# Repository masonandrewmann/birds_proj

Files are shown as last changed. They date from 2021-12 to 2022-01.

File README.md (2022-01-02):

# Communication via Sound with Bird-Like Autonomous Agents
## Final Project for Interactive Music, MUSI 4670/6002 

### Video Demo: 
https://youtu.be/LeYnbbA8mWI

### Project Paper: 
https://github.com/masonandrewmann/birds_proj/blob/34f84f54d7a54a15b16ec71c6c1e4912c616cff0/final_paper.pdf

### Libraries used:

MCP DAC Library: https://github.com/exscape/electronics/tree/master/Arduino/Libraries/DAC_MCP49xx

BasicLinearAlgebra (to easily perform matrix multiplication in Markov Model): https://github.com/tomstewart89/BasicLinearAlgebra

Goertzel Algorithm inspiration: https://github.com/jacobrosenthal/Goertzel

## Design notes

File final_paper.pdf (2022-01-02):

# Communication via Sound with Bird-Like Autonomous Agents

### Mir Jeffres

Georgia Institute of Technology Atlanta, Georgia, USA

### Mason Mann

Georgia Institute of Technology Atlanta, Georgia, USA
mmann33@gatech.edu

ACM Reference Format:
Mir Jeffres and Mason Mann. 2021. Communication via Sound with Bird-Like Autonomous Agents. In Proceedings of ACM Conference (Conference’17). ACM, New York, NY, USA, 2 pages. https://doi.org/10.1145/nnnnnnn.nnnnnnn

### 1 CONCEPT

The concept of our project was to create a group of autonomous, self-contained physical objects that could sing to each other and hear each other singing and respond according to computational algorithms. The idea was that simple behavior could be programmed into each agent and that together, complex group behavior would arise. Agents would switch between a state where they are listening, and another state where they respond. During the listening state they would determine the loudest note that they heard and use that as the input to a first order Markov model. With all the agents separately playing single notes from the same Markov model, the idea was that the whole group behavior would be similar to that of a single entity playing a single Markov-model. We considered this to be a sort of “distributed Markov model.” Additionally the average loudness that each agent is hearing at any given time will have an effect on the way it plays the notes. When the average loudness is higher, they will shorten their listening period, playing notes more often and moving through the markov model more quickly, and they will also play shorter notes creating a frantic feel. Additionally there would be a few ways that a user could interact and guide the behavior. The primary method of interaction is simply picking up the agents and moving them, if they are further apart from each other they will not hear each other as loudly, decreasing the average loudness and when far enough away, making some agents not interact at all. Another way that the users interact is through a special agent called the “Leader Bird.” This agent plays a special command pitch when a button on it is pressed. All of the follower agents have four separate Markov models built on different pitch-class sets and they all start on the same one. When an agent hears this command pitch they will move to the next pitch-class set. Since they might not all hear the command pitch depending on where they are placed, they will likely begin to drift into groups playing different pitch-class sets moving from a state of consonance in the beginning of the piece to a polytonal cloud as time goes on.

Permission to make digital or hard copies of all or part of this work for personal or classroom use is granted without fee provided that copies are not made or distributed for profit or commercial advantage and that copies bear this notice and the full citation on the first page. Copyrights for components of this work owned by others than ACM must be honored. Abstracting with credit is permitted. To copy otherwise, or republish, to post on servers or to redistribute to lists, requires prior specific permission and/or a fee. Request permissions from permissions@acm.org.
Conference’17, July 2017, Washington, DC, USA
© 2021 Association for Computing Machinery.
ACM ISBN 978-x-xxxx-xxxx-x/YY/MM. . . $15.00 https://doi.org/10.1145/nnnnnnn.nnnnnnn

### 2 CONTEXT

The work that most directly inspired this project was Felix Hess’s Electronic Sound Creatures. In his project, one hundred physical autonomous agents were created to perform in smaller groups. These agents had wheels, motors, microphones and speakers and were able to listen to each other, respond and perform crude localizations moving towards and away from each other depending on the notes heard. They were implemented in a fully analog manner using band-pass filters and op-amp integrators to detect pitches, which made them very computationally limited. Our project extends this concept in a few ways. First, it is implemented with an embedded microcontroller, allowing more pitches to be detected as well as allowing more complex rules to guide each agent’s response to them. Additionally, while Hess’s work was fully generative, we wanted to incorporate a way for audiences to interact with our project. Rather than giving the agents wheels and allowing them to move themselves, they are stationary and must be moved by the audience. Picking them up and moving them varying distances from each other will allow them to hear each other more or less which factors into the algorithm guiding their behavior. Another concept that informed this project was IOT implementations of Data-Over-Sound. The idea that complex data can be sent between agents through the physical medium of sound rather than more complex protocols such as bluetooth or network connection is very interesting. The final concept that inspired this was Craig Reynold’s Boids algorithm, for modeling bird flocking behavior. It was a landmark work in complex behaviors arising from autonomous agents with simple rules guiding behavior so we thought it would be interesting to explore similar concepts in the sound domain.

### 3 IMPLEMENTATION

The project was implemented by creating nine autonomous agents housed in 3.5”x3.5”x5” wooden boxes. Each one contains a PCB containing a speaker, a microphone, an ATMEGA328 microcontroller, a DAC chip, and circuitry for scaling the microphone signal, driving the speaker, conditioning power and conditioning a few GPIO pins on the microcontroller to read switch data and drive LEDs. A schematic of the PCB is included in the .zip along with the project code. An NJM2073 dual power amplifier chip was used in a push/pull configuration to allow for maximum power efficiency in driving the speaker. The DAC chip used was a MCP4901 8-bit DAC chosen for its price, simplicity and ability to be driven over I2C. ATMEGA328 chips were chosen because of their cost and ease of programming through the Arduino IDE and their extensive documentation. In the end they proved to be a poor choice for audio uses. Large sacrifices had to be made in sampling rate, buffer size and wavetable size and still almost all of the memory was used. To code the ATMEGA328s, code was written in the Arduino IDE and flashed to the chip through an Arduino Uno, the board that allows

Conference’17, July 2017, Washington, DC, USA | Mir Jeffres and Mason Mann

for user interfacing with ATMEGA328 chips. The pitch detection
section of the code used a Goertzel algorithm. This algorithm can
be thought of as a single-bin FFT. We didn’t have the computation to spare to run an entire FFT and since we were only looking for a finite number of discrete pitches it made sense to only look for those pitches. The bin size is a function of both the sample rate and the buffer size. Since we didn’t have the memory to spare for a large buffer we kept a short buffer and dropped the sample rate incredibly low to 2500Hz. This allowed us a resolution of 10Hz per bin which was small enough that adjacent notes didn’t overlap. We weren’t playing any frequencies over 1000Hz so the low sample rate shouldn’t really affect the sound of the system. During the listen period the microcontroller constantly samples the magnitude of all the notes it is listening for and keeps track of the maximum over that period. Then at the end of the period it takes the maximum value of this maximum array, essentially finding what the loudest note heard over the entire listening period was and uses that note to feed the markov model. The average of this maximum array is also used to scale the length of each listening period as well as the length of an ASR envelope on each note. Resulting in a higher density of shorter notes when the agent hears a lot of sound. Within the code, a Markov chain was implemented to determine the next note from the previous note the agent “heard” through the microphone. The Markov implementation uses the basic idea of a Markov chain that is taught in linear algebra where there is a transition matrix that has all rows and columns summing to 1 and contains the percent chance of each transition between notes happening, multiplied by the current state (in this case, a column matrix which contains one 1 value for the note it heard, and the rest zeros). In this project, there were five total notes, so the transition matrix was a 5x5 matrix and the current state matrix was 5x1. To determine the next note from the outputted 5x1 matrix of probabilities of the next note, an array was created by multiplying each output chance from the 5x1 matrix by 100 to give integer values that summed to 100 for the column, and then duplicating each possible note in another array n times, where n was the row of the matrix * 100. This gave a 100 point array with each possible note, and a random number between 0 and 99 was used to index that array to get the next note out. This algorithm seems complicated, but was relatively easy to implement and allows for easier manipulation of the Markov model than using a Markov library. The only library used in this implementation was one to perform the matrix multiplication to avoid writing two more loops.

### 4 EVALUATION

Musically, this piece is not particularly successful in its current state. It is an interesting concept and behavior has begun to arise but it would be hard to describe the sonic result as aesthetically beautiful. Some combination of low sample rate, small wavetables, imperfect power amplifier and imperfect speaker mounting distorted what should have been perfect sine waves into something closer to a distorted sawtooth. The fundamental frequencies are preserved so the agents are able to communicate with each other but the sonic result is not as pleasant to listen to. The main things learned from the difficulties in the project were about developing and iterating when building physical objects. We often were slowed down by certain parts of the project not working when we could have worked on them more in parallel. We didn’t begin implementing the Markov behavior until the units worked, which took a while as there was a lot of soldering, laser cutting and a few iterations of circuit boards. Looking back, this behavior could have been developed in something like Max and then just ported over once the physical objects were functional. Debugging behavior on microcontrollers that have no serial port and need to be removed from the board to be programmed proved to be very tedious. While we were very excited to be outside of the Max environment and creating something real that didn’t need a laptop to run, the power of Max and similar tools as a method of rapid prototyping of behavior is something that we could have benefited from in the early stages of the project. Another issue that we ran into was the quality of the PCBs used. They were milled on campus using a desktop CNC machine. This allowed us to quickly create iterations but the boards didn’t have solder mask, making them difficult to solder to and causing quite a few shorts. This increased the amount of time spent debugging hardware by quite a bit and in the end we only had 4 out of the 9 units totally working given time constraints. The final issue with the system was that instead of running on battery power they currently are running on 9v DC wall wart plugs. In general the interactivity of the system is not quite where we would like it to be yet. The user is able to pick up the agents and move them around but not very far as they are still running on wired power. The thresholds and scaling based on how loud the notes each unit hears are could use some fine-tuning as well to help the user really feel that they are having an effect on the music. The pitch-class set switching from the leader bird does work however, allowing the user a piece of very direct control. Overall we view this project not as a complete piece but as a stepping stone. The Markov model works great and the units are all able to speak to each other but a lot of kinks in the system need to be worked out and the user interactivity absolutely needs to be explored a little more deeply.

### 5 REFERENCES

[1] Arm Ltd. Why Data-Over-Sound Should Be a Part of Any IoT En-
gineer’s Toolbox. Arm | The Architecture for the Digital World. Re-
trieved December 7, 2021 from https://www.arm.com/resources/whitepaper/data-over-sound
[2] Craig Reynolds. Boids (Flocks, Herds, and Schools: a Distributed Behavioral Model). Retrieved December 7, 2021 from https://www.red3d.com/cwr/boids/
[3] 2000. Electronic Sound Creatures. In Prerational Intelligence: Adaptive Behavior and Intelligent Systems Without Symbols and Logic. Springer, 452–457. DOI:https://doi.org/10.1007/978-94-010-0870-962

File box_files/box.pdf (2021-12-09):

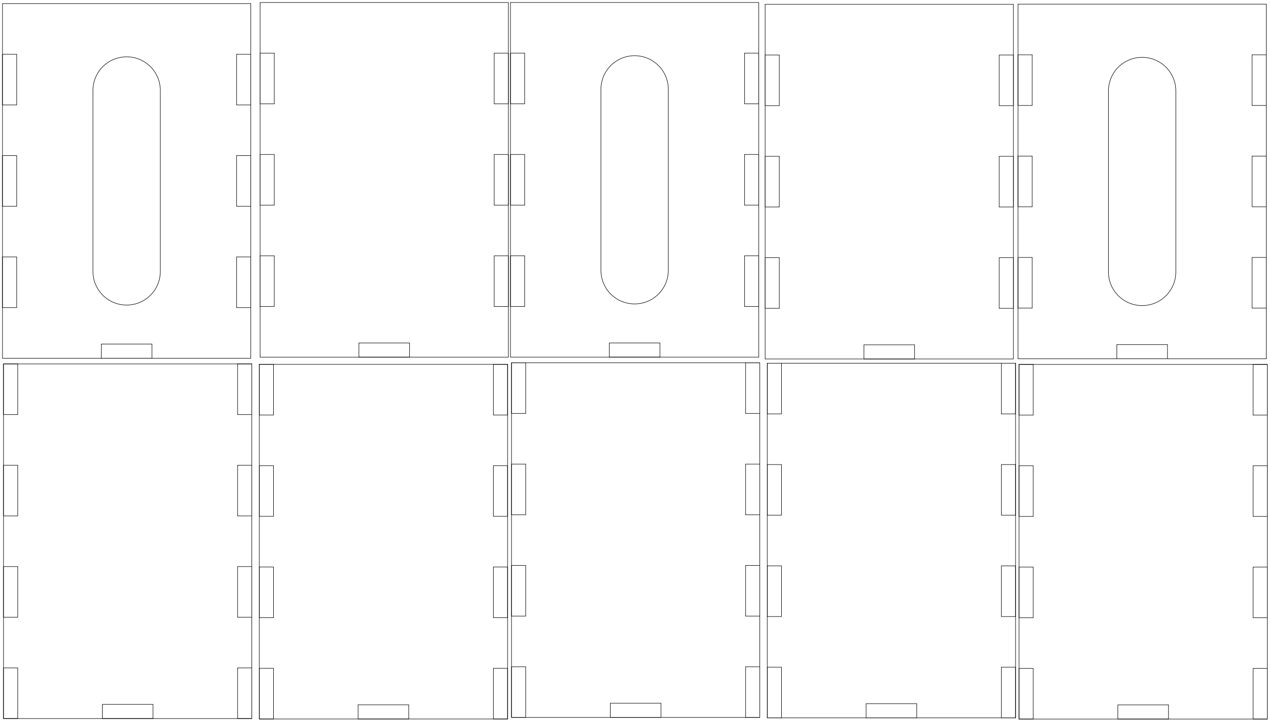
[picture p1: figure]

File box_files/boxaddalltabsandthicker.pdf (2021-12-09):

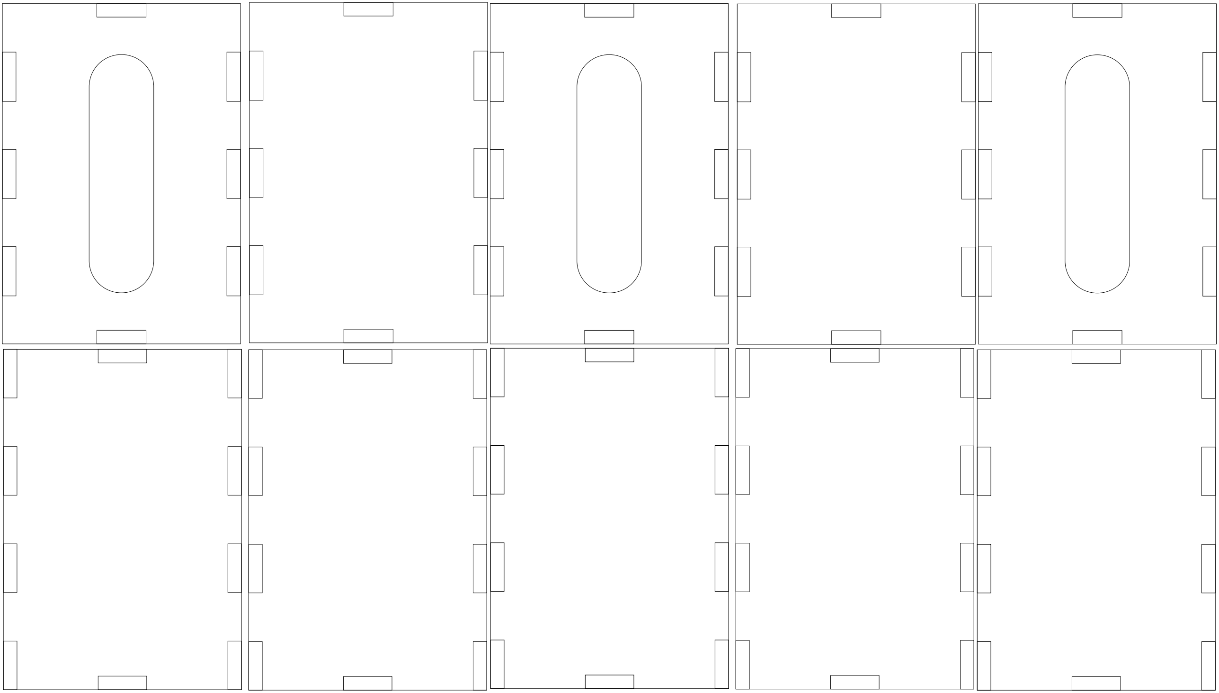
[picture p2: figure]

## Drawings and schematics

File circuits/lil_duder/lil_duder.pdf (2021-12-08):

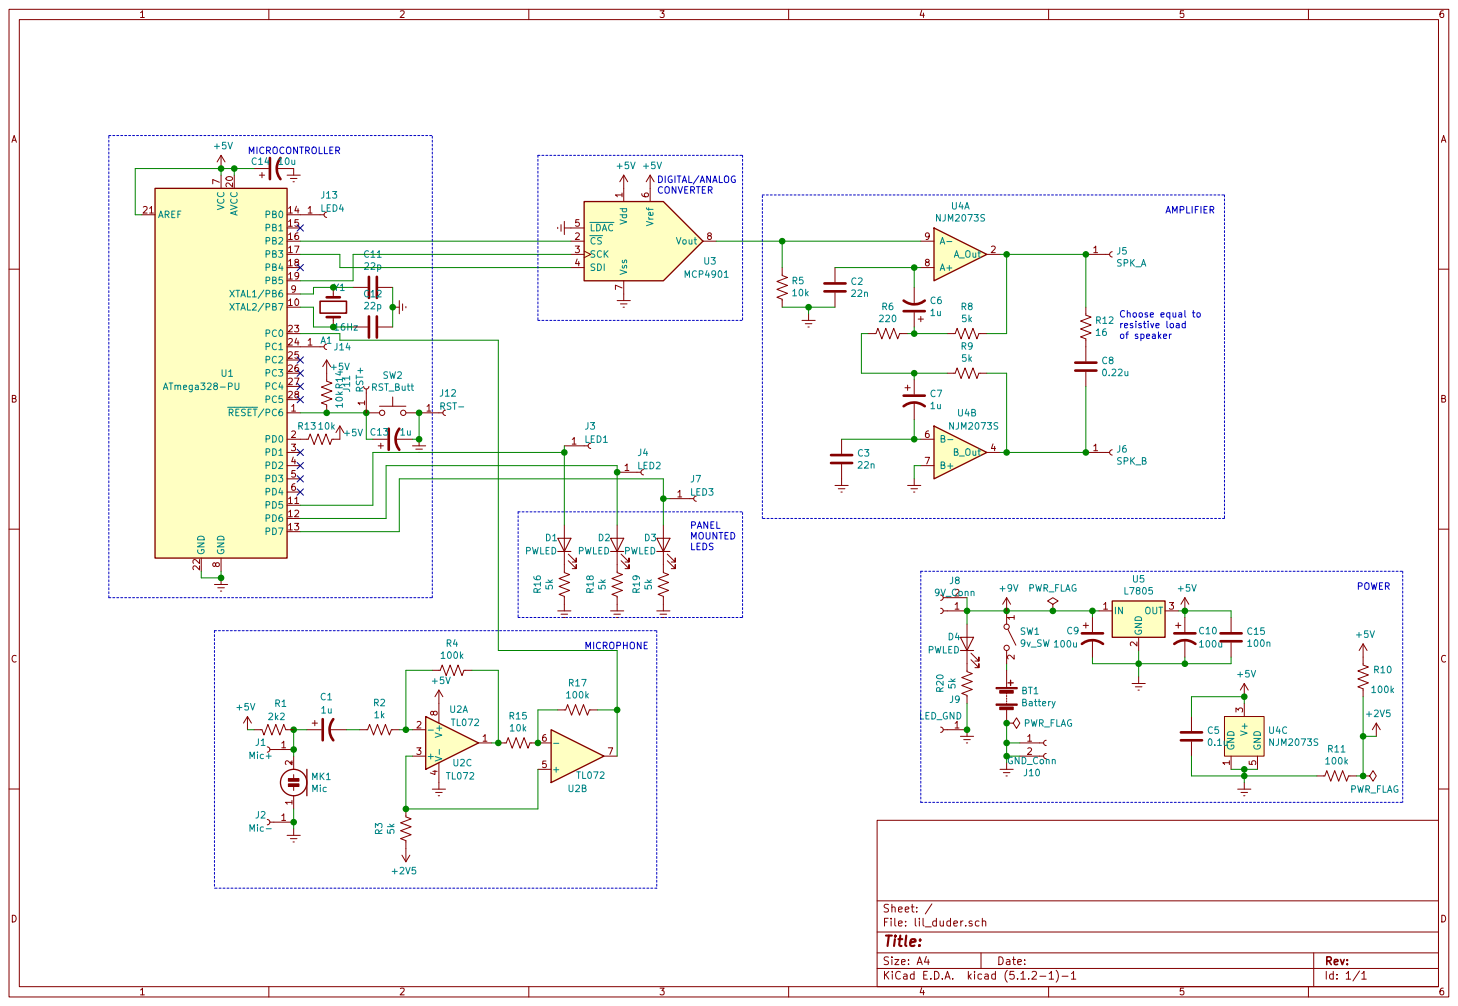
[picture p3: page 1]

LED_GND R20 5k DIGITAL/ANALOG CONVERTER MICROCONTROLLER

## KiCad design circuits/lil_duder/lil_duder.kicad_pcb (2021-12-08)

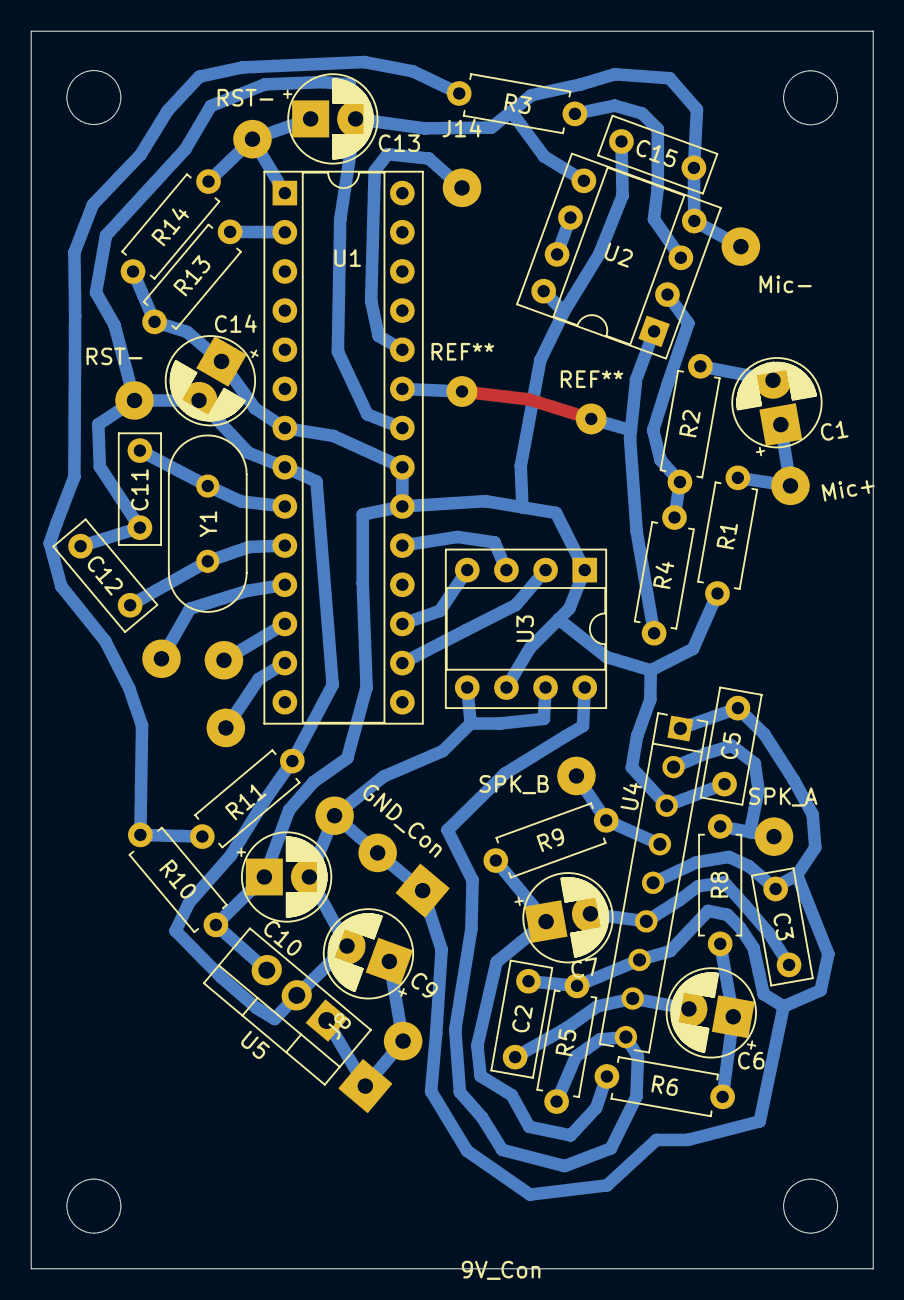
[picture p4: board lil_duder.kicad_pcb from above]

Board: 2 copper layers, 54.6 x 80.3 mm, 44 parts (0 on the bottom side), 28 nets.

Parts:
C1, C6, C7, C13: 1u; CP_Radial_D5.0mm_P2.0mm_Bigger_Holes
C2, C3: 22n; C_Rect_L7.0mm_W2.5mm_P5.00mm
C5: 0.1u; C_Rect_L7.0mm_W2.5mm_P5.00mm
C9, C10: 100u; CP_Radial_D5.0mm_P2.0mm_Bigger_Holes
C11, C12: 22p; C_Rect_L7.0mm_W2.5mm_P5.00mm
C14: 10u; CP_Radial_D5.0mm_P2.0mm_Bigger_Holes
C15: 100n; C_Rect_L7.0mm_W2.5mm_P5.00mm
J1: Mic+; SolderWirePad_1x01_Drill1mm
J2: Mic-; SolderWirePad_1x01_Drill1mm
J3: LED1; SolderWirePad_1x01_Drill1mm
J4: LED2; SolderWirePad_1x01_Drill1mm
J5: SPK_A; SolderWirePad_1x01_Drill1mm
J6: SPK_B; SolderWirePad_1x01_Drill1mm
J7: LED3; SolderWirePad_1x01_Drill1mm
J8: 9V_Conn; SolderWirePad_1x02_P3.81mm_Drill1mm
J9: LED_GND; SolderWirePad_1x01_Drill1mm
J10: GND_Conn; SolderWirePad_1x02_P3.81mm_Drill1mm
J11: RST+; SolderWirePad_1x01_Drill1mm
J12: RST-; SolderWirePad_1x01_Drill1mm
J14: A1; SolderWirePad_1x01_Drill1mm
R1: 2k2; R_Axial_DIN0207_L6.3mm_D2.5mm_P7.62mm_Horizontal
R2: 1k; R_Axial_DIN0207_L6.3mm_D2.5mm_P7.62mm_Horizontal
R3, R8, R9: 5k; R_Axial_DIN0207_L6.3mm_D2.5mm_P7.62mm_Horizontal
R4, R10, R11: 100k; R_Axial_DIN0207_L6.3mm_D2.5mm_P7.62mm_Horizontal
R5, R13, R14: 10k; R_Axial_DIN0207_L6.3mm_D2.5mm_P7.62mm_Horizontal
R6: 220; R_Axial_DIN0207_L6.3mm_D2.5mm_P7.62mm_Horizontal
U1: ATmega328-PU; DIP-28_W7.62mm_Socket
U2: TL072; DIP-8_W7.62mm_Socket
U3: MCP4901; DIP-8_W7.62mm_Socket
U4: NJM2073S; SIP-9_21.54x3mm_P2.54mm
U5: L7805; TO-220-3_Vertical
Y1: 16Hz; Crystal_HC49-4H_Vertical

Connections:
+2V5: R3.2, R10.1, R11.1
+5V: C5.1, C10.1, C14.1, C15.1, R1.1, R10.2, R13.1, R14.2, U1.7, U1.20, U1.21, U2.8, U3.1, U3.6, U4.3, U5.3
+9V: C9.1, J8.1, J8.2, U5.1
Earth: C2.2, C3.2, C5.2, C9.2, C10.2, C11.1, C12.1, C13.2, C14.2, C15.2, J2.1, J9.1, J10.1, J10.2, J12.1, R5.1, R11.2, U1.8, U1.22, U2.4, U2.5, U3.5, U3.7, U4.1, U4.5, U4.7, U5.2
unnamed: C1.1, J1.1, R1.2
unnamed: C1.2, R2.2
unnamed: C2.1, C6.2, U4.8
unnamed: C3.1, C7.2, U4.6
unnamed: C6.1, R6.1, R8.2
unnamed: C7.1, R6.2, R9.2
unnamed: J6.1, R9.1, U4.4
unnamed: C11.2, U1.9, Y1.1
unnamed: C12.2, U1.10, Y1.2
unnamed: C13.1, J11.1, R14.1, U1.1
unnamed: J3.1, U1.11
unnamed: J4.1, U1.12
unnamed: J7.1, U1.13
unnamed: J5.1, R8.1, U4.2
unnamed: J14.1, U1.24
unnamed: R2.1, R4.2, U2.2
unnamed: R3.1, U2.3
unnamed: R4.1, U1.23, U2.1
unnamed: R5.2, U3.8, U4.9
unnamed: R13.2, U1.2
unnamed: U1.16, U3.2
unnamed: U1.17, U3.4
unnamed: U1.19, U3.3
unnamed: U2.6, U2.7

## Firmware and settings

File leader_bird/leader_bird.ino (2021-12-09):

#include "TimerOne.h"
#include "AsyncAnalog.h"
#include <SPI.h>
#include <DAC_MCP49xx.h>
#define SS_PIN 10 //define chip select pin
#define TABLESIZE 512
#include <MarkovChain.h>

#define LED_1 PD7
#define LED_2 PD6
#define BUTTON_PIN PD5
#define LED_4 PB0

#define printf(fmt, ...) \
  snprintf(_printfBuffer, 64, fmt, ##__VA_ARGS__);\
  Serial.print(_printfBuffer);
  

int SineValues[TABLESIZE]; 
float pointerInc;
float pointerVal = 0;
int outVal;

int outInd = 0;
//float freqs [][] = {{261.63, 293.66, 329.63, 392.00, 440.00, 523.25},
//                  {329.63, 369.99, 392.00, 493.88, 523.25},
//                  {207.65, 261.63, 311.13, 349.23, 369.99},
//                  {466.16, 523.25, 587.33, 698.46, 783.99}};
float freqs [] = {261.63, 293.66, 329.63, 392.00, 440.00, 523.25};
float leaderFreq = 1108.73;




//Set up the DAC
DAC_MCP49xx dac(DAC_MCP49xx::MCP4901, SS_PIN);

//Set up ASR envelope
//int attack = 500;
//int sus = 1000;
//int decay = 1000;
int envTimes[4] = {500, 500, 500, 0}; // [attack, sustain, release, PLACEHOLDER]
float envVal = 1;
boolean noteActive = false;
unsigned long noteEnd = 0;
byte envState = 0; // 0 for attack, 1 for sustain, 2 for release, 3 for inactive
unsigned long sectionStart = 0;
unsigned long sectionEnd = 0;

//note clock
unsigned long nextNote = 0;

//note control
boolean listening = true;
unsigned long listenTimer = 2000;
int listenLength = 2000;
byte listenCount = 0;
float outFreq = 1108.73;


char _printfBuffer[64]; 

// Constants
constexpr int inputPin = A0; // A0 connected to microphone
//constexpr int bufferSize = 256;
constexpr int samplingRate = 10000; // 5khz
//constexpr float targetFreq = 200; // 200hz
constexpr float threshold = 30;

//target frequencies:
//constexpr float targetC4 = 261.63; // C4
//constexpr float targetD4 = 293.66; // D4
//constexpr float targetE4 = 329.63; // E4
//constexpr float targetG4 = 392.00; // G4
//constexpr float targetA4 = 440.00; // A4
//constexpr float targetC5 = 523.25; // C5
float mags[6];
float magsMax[6] = {0, 0, 0, 0, 0, 0};

float pitches[6];

unsigned int writePtr = 0;
//uint16_t adcBuffer[bufferSize];

ISR(ADC_vect) {
  //read from microphone
//  adcBuffer[writePtr] = analogReadGetValue();
//  writePtr = (writePtr + 1) % bufferSize;
  //output to speaker
//  if (noteActive){
    cycle();
    dac.output(outVal);
//  } else {
//    dac.output(0);
//  } 
}

// Just so part of our program doesn't get interruptted
struct int_guard {
  int_guard() { noInterrupts(); }
  ~int_guard() { interrupts(); }
};

// Group everything here
//template<typename FLOATING = float, typename SAMPLE = uint16_t>
//struct GoertzelBuffer {
//  SAMPLE currentSamples[bufferSize];
//  FLOATING coeff, Q1, Q2, sine, cosine;
//
//  void from(SAMPLE buffer[bufferSize], int startIndex = 0) {
//    memcpy(currentSamples, buffer + startIndex, sizeof(SAMPLE) * (bufferSize - startIndex));
//    memcpy(currentSamples + startIndex, buffer, sizeof(SAMPLE) * startIndex);
//  }
//
//  void init(FLOATING targetFreq) {
//    int k;
//    FLOATING floatN;
//    FLOATING omega;
//
//    floatN = (FLOATING) bufferSize;
//    k = (int) (0.5 + ((floatN * targetFreq) / samplingRate));
//    omega = (2.0 * PI * k) / floatN;
//    sine = sin(omega);
//    cosine = cos(omega);
//    coeff = 2.0 * cosine;
//  }
//
//
//  void ProcessSample(SAMPLE sample) {
//    FLOATING Q0;
//    Q0 = coeff * Q1 - Q2 + (FLOATING) sample;
//    Q2 = Q1;
//    Q1 = Q0;
//  }
//
//  void updateFreq(FLOATING newFreq){
//    int k;
//    FLOATING floatN;
//    FLOATING omega;
//
//    floatN = (FLOATING) bufferSize;
//    k = (int) (0.5 + ((floatN * newFreq) / samplingRate));
//    omega = (2.0 * PI * k) / floatN;
//    sine = sin(omega);
//    cosine = cos(omega);
//    coeff = 2.0 * cosine;
//  }
//
//  /* Basic Goertzel */
//  /* Call this routine after every block to get the complex result. */
//  void GetRealImag(FLOATING *realPart, FLOATING * imagPart) {
//    *realPart = (Q1 - Q2 * cosine);
//    *imagPart = (Q2 * sine);
//  }
//
//  /* Optimized Goertzel */
//  /* Call this after every block to get the RELATIVE magnitude squared. */
//  FLOATING GetMagnitudeSquared(void) {
//    FLOATING result;
//
//    result = Q1 * Q1 + Q2 * Q2 - Q1 * Q2 * coeff;
//    return result;
//  }
//
//  void ResetGoertzel(void) {
//    Q2 = 0;
//    Q1 = 0;
//  }
//
//  float processAll() {
//    ResetGoertzel();
//    for (const auto& sample : currentSamples) {
//      ProcessSample(sample);
//    }
//    auto mag2 = GetMagnitudeSquared();
//    return sqrt(mag2);
//  }
//};
//
//GoertzelBuffer<> goertzel {};

void cycle(){
  pointerInc = TABLESIZE * (outFreq / samplingRate);
  //grab sample from wavetable
  outVal = SineValues[(int)pointerVal];

//  //check envelope state
//  if (millis() > sectionEnd) {
//    envState++;
//    sectionStart = millis();
//    sectionEnd = sectionStart + envTimes[envState];
//  }
//  //determine envelope value
//  switch (envState){
//    case 0: //attack
//      envVal = (float)(millis() - sectionStart)  / (float)(sectionEnd - sectionStart);
//    break;
//    case 1: //sustain
//      envVal = 1;
//    break;
//
//    case 2: //release
//      envVal = 1 + (float)(millis() - sectionStart) * (-1) / (float)(sectionEnd - sectionStart);
//    break;
//    case 3: //end the note
//      noteActive = 0;
//      listening = true;
//      digitalWrite(LED_1, LOW);
//    break;
//  }
//  //multiply by envelope value
  outVal *= envVal;
  //increment wavetable pointer
  pointerVal += pointerInc;
  if(pointerVal > TABLESIZE) pointerVal -= TABLESIZE;
}


char states[] = {'a','b','c','d','e'};
int lenStates = 5; //CHANGE THIS MANUALLY IF WE INCREASE THE NUMBER OF NOTES

void trigNote(float freq, int atk, int sus, int rel){
  digitalWrite(LED_1, HIGH);
  envTimes[0] = atk;
  envTimes[1] = sus;
  envTimes[2] = rel;
  outFreq = freq;
  pointerInc = TABLESIZE * (outFreq / samplingRate);
  noteActive = true;
  noteEnd = millis() + envTimes[0] + envTimes[1] + envTimes[2];
  sectionStart = millis();
  sectionEnd = sectionStart + envTimes[0];
  envState = 0;
}

void setup() {
  //initialize GPIO pins
  pinMode(LED_BUILTIN, OUTPUT);
  pinMode(LED_1, OUTPUT);
  pinMode(LED_2, OUTPUT);
  pinMode(BUTTON_PIN, INPUT);
  pinMode(LED_4, OUTPUT);
  digitalWrite(LED_2, HIGH);
  
  analogReadSetup(inputPin);
  Timer1.initialize(1000000 / samplingRate);
  Timer1.attachInterrupt(analogReadStart);
  Serial.begin(115200);
//  trainMarkov();

    // calculate sine wavetable
  float RadAngle;                           // Angle in Radians
  for(int MyAngle=0;MyAngle<TABLESIZE;MyAngle++) {
    RadAngle= MyAngle*(2*PI)/TABLESIZE;               // angle converted to radians
    SineValues[MyAngle]=(sin(RadAngle)*127)+128;  // get the sine of this angle and 'shift' to center around the middle of output voltage range
  }

  //
  pointerInc = TABLESIZE * (freqs[outInd] / samplingRate);
  pointerVal = map(0, 0, TWO_PI, 0, TABLESIZE - 1);

//starts looking for C4
//  goertzel.init(261.63);

  delay(1000);
}

void loop() {
  {
    int_guard guard {};
//    goertzel.from(adcBuffer);
  }
 
  //determine maximum magnitudes over listening period
//  if (listening){
//  for (int i = 0; i < 6; i++){
//    goertzel.updateFreq(freqs[i]);
//     mags[i] = (goertzel.processAll() * 10);
//    if (mags[i] > magsMax[i]) magsMax[i] = mags[i];
//  }
//  }
  //print out magnitudes of all frequencies tested
//  Serial.print("C4: ");
//  Serial.print(mags[0]);
//  Serial.print(" D4: ");
//  Serial.print(mags[1]);
//  Serial.print(" E4: ");
//  Serial.print(mags[2]);
//  Serial.print(" G4: ");
//  Serial.print(mags[3]);
//  Serial.print(" A4: ");
//  Serial.print(mags[4]);
//  Serial.print(" C5: ");
//  Serial.println(mags[5]);


  //determine what note to play
//  if( millis() > listenTimer && !noteActive){
//    float chosenFreq = 0;
//    //find max value of array and its corresponding frequency index
//    float maxVal = magsMax[0];
//    byte maxInd = 0;
//    for (int i = 0; i < (sizeof(magsMax) / sizeof(magsMax[0])); i++) {
//      if (magsMax[i] > maxVal){
//        maxVal = magsMax[i];
//        maxInd = i;
//      }
//    }
//    //if max value is above a threshold, play a note
//    if (maxVal > 4000){
////      chosenFreq = freqs[maxInd] * 1.0595; //one semitone up from played note
//      chosenFreq = freqs[(maxInd+1)%((sizeof(magsMax) / sizeof(magsMax[0])))];
//      trigNote(chosenFreq, 500, 1000, 500);
//      listening = false;
//      listenCount = 0;
//    } else if(listenCount > 3){
//      //play random note if it hasnt sang in a while
//      byte randInd = random((sizeof(magsMax) / sizeof(magsMax[0])));
//      trigNote(freqs[randInd], 500, 1000, 500);
//      listenCount = 0;
//      listening = false;
//    }
//    else {
//      //don'tt play a note
//      listenTimer += listenLength;
//      listenCount++;
//      listening = true;
//    }
//    for (int i = 0; i < (sizeof(magsMax) / sizeof(magsMax[0])); i++) {
//      magsMax[i] = 0;
//    }
//    
//  }

 
//  if (millis() > nextNote){
//    trigNote(200, 10, 50, 50);
//    nextNote = millis() + 3500;
//  }
//  bool toneDetected = magnitude > threshold;

//  printf("C4: %d, D4: %d, E4: %d, G4: %d, A4: %d, C5: %d\n", (int)(mags[0] * 100), (int)(mags[1] * 100), (int)(mags[2] * 100), (int)(mags[3] * 100), (int)(mags[4] * 100), (int)(mags[5] * 100)); 

//  once the tone is detected, play the next tone.
  
  //nextPitch();
 
  
  // Delay for a little bit
//  delay(300);
  int pinVal = digitalRead(BUTTON_PIN);
  if (pinVal == LOW){
      envVal = 1;
  } else {
    envVal = 0;
  }
//    trigNote(leaderFreq, 500, 2000, 500);
}

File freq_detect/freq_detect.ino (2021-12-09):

#include "TimerOne.h"
#include "AsyncAnalog.h"
#include <SPI.h>
#include <DAC_MCP49xx.h>
#define SS_PIN 10 //define chip select pin
#define TABLESIZE 50
#include <MarkovChain.h>
#include <BasicLinearAlgebra.h>

using namespace BLA;


#define LED_1 PD5
#define LED_2 PD6
#define BUTTON_PIN PD7
#define LED_4 PB0

#define printf(fmt, ...) \
  snprintf(_printfBuffer, 64, fmt, ##__VA_ARGS__);\
  Serial.print(_printfBuffer);
  
  // initialize possible nums with length 100 and 0s in all inds
  char possibleNotes[100];
  
int SineValues[TABLESIZE]; 
float pointerInc;
float pointerVal = 0;
int outVal;

int outInd = 0;
int curSection = 0;
float freqs [4][5] = {{261.63, 293.66, 329.63, 392.00, 440.00},
                  {329.63, 369.99, 392.00, 493.88, 523.25},
                  {207.65, 261.63, 311.13, 349.23, 369.99},
                  {466.16, 523.25, 587.33, 698.46, 783.99}};
float leaderFreq = 1108.73;
float leaderMag = 0;

// defining the possible current frequencies with curSection - curSection must be updated every time it hears the leader freq
float curFreqs [5];
float curFreqsPlusLeader[6];

char curGlobalNote = 'a';
// each letter corresponds to a frequency, not the actual note name just placeholders for it to be human readable later.
char states[] = {'a','b','c','d','e'};

// important note: each row and each column must sum to 1 
// AND must not go over 2 points after the decimal. 
// you are doing sudoku
Matrix<5,5> tMatrix = {0.2,  0.25,  0.25, 0.1,  0.2,
                       0.2,  0.1,   0.2,  0.3,  0.2,
                       0.2,  0.25,  0.25, 0.3,  0,
                       0.3,  0.4,   0,    0.3,  0,
                       0.1,  0,     0.3,  0,    0.6};


// attack, sustain, and release global variables that can be changed based on how loud things are around it. setting defaults here
float attackGlobal = 500;
float sustainGlobal = 1000;
float releaseGlobal = 500;

//Set up the DAC
DAC_MCP49xx dac(DAC_MCP49xx::MCP4901, SS_PIN);

//Set up ASR envelope
//int attack = 500;
//int sus = 1000;
//int decay = 1000;
int envTimes[4] = {500, 500, 500, 0}; // [attack, sustain, release, PLACEHOLDER]
float envVal = 1;
boolean noteActive = false;
unsigned long noteEnd = 0;
byte envState = 0; // 0 for attack, 1 for sustain, 2 for release, 3 for inactive
unsigned long sectionStart = 0;
unsigned long sectionEnd = 0;
float maxVal;

//note clock
unsigned long nextNote = 0;

//note control
boolean listening = true;
unsigned long listenTimer = 2000;
unsigned long listenTimer2 = 2000;

unsigned long listenLength = 2000;
byte listenCount = 0;
float outFreq = 100.00;

boolean leaderTimeout = false;
unsigned long leaderTimer = 10000;

char _printfBuffer[64]; 

// Constants
constexpr int inputPin = A0; // A0 connected to microphone
constexpr int bufferSize = 256;
constexpr int samplingRate = 2500; // 1250 Nyquist
//sampling rate is mainly so low to have precise frequency resolution on the Goertzel algorithm. bin size = Fs/N = 2500 / 256 = 9.76Hz
//time resolution is 256 * 2500 = 0.1024ms

//constexpr float targetFreq = 200; // 200hz
constexpr float threshold = 30;

//target frequencies:
//constexpr float targetC4 = 261.63; // C4
//constexpr float targetD4 = 293.66; // D4
//constexpr float targetE4 = 329.63; // E4
//constexpr float targetG4 = 392.00; // G4
//constexpr float targetA4 = 440.00; // A4
//constexpr float targetC5 = 523.25; // C5
float mags[6];
float magsMax[6] = {0, 0, 0, 0, 0, 0};

float pitches[6];

unsigned int writePtr = 0;
uint16_t adcBuffer[bufferSize];

ISR(ADC_vect) {
  //read from microphone
  adcBuffer[writePtr] = analogReadGetValue();
  writePtr = (writePtr + 1) % bufferSize;
  //output to speaker
  if (noteActive){
    cycle();
    dac.output(outVal);
  } else {
    dac.output(0);
  } 
}

// Just so part of our program doesn't get interruptted
struct int_guard {
  int_guard() { noInterrupts(); }
  ~int_guard() { interrupts(); }
};

// Group everything here
template<typename FLOATING = float, typename SAMPLE = uint16_t>
struct GoertzelBuffer {
  SAMPLE currentSamples[bufferSize];
  FLOATING coeff, Q1, Q2, sine, cosine;

  void from(SAMPLE buffer[bufferSize], int startIndex = 0) {
    memcpy(currentSamples, buffer + startIndex, sizeof(SAMPLE) * (bufferSize - startIndex));
    memcpy(currentSamples + startIndex, buffer, sizeof(SAMPLE) * startIndex);
  }

  void init(FLOATING targetFreq) {
    Serial.print(targetFreq);
    int k;
    FLOATING floatN;
    FLOATING omega;

    floatN = (FLOATING) bufferSize;
    k = (int) (0.5 + ((floatN * targetFreq) / samplingRate));
    omega = (2.0 * PI * k) / floatN;
    sine = sin(omega);
    cosine = cos(omega);
    coeff = 2.0 * cosine;
  }

  void ProcessSample(SAMPLE sample) {
    FLOATING Q0;
    Q0 = coeff * Q1 - Q2 + (FLOATING) sample;
    Q2 = Q1;
    Q1 = Q0;
  }

  void updateFreq(FLOATING newFreq){
    int k;
    FLOATING floatN;
    FLOATING omega;

    floatN = (FLOATING) bufferSize;
    k = (int) (0.5 + ((floatN * newFreq) / samplingRate));
    omega = (2.0 * PI * k) / floatN;
    sine = sin(omega);
    cosine = cos(omega);
    coeff = 2.0 * cosine;
  }

  /* Basic Goertzel */
  /* Call this routine after every block to get the complex result. */
  void GetRealImag(FLOATING *realPart, FLOATING * imagPart) {
    *realPart = (Q1 - Q2 * cosine);
    *imagPart = (Q2 * sine);
  }

  /* Optimized Goertzel */
  /* Call this after every block to get the RELATIVE magnitude squared. */
  FLOATING GetMagnitudeSquared(void) {
    FLOATING result;

    result = Q1 * Q1 + Q2 * Q2 - Q1 * Q2 * coeff;
    return result;
  }

  void ResetGoertzel(void) {
    Q2 = 0;
    Q1 = 0;
  }

  float processAll() {
    ResetGoertzel();
    for (const auto& sample : currentSamples) {
      ProcessSample(sample);
    }
    auto mag2 = GetMagnitudeSquared();
    return sqrt(mag2);
  }
};
GoertzelBuffer<> goertzel {};

// takes in magnitudes from magsMax which is a global variable and returns A MULTIPLIER FOR THE DEFAULT //////a, s, and r values
float densityOfNotes(float mags4density[]){
  float totalLoud = 0;
//  for(int i=0; i<(sizeof(mags4density)/sizeof(mags4density[0])); i++){
  for (int i=0; i<5; i++){
    totalLoud = totalLoud + mags4density[i];
  }
  Serial.print("total loud: ");
  Serial.print(totalLoud);
  Serial.println();
  // the higher the totalLoud, the smaller the a, s, and r values are. maybe
  // we are assuming 10000 is a medium loud sound.

  // default attack: 500
  // default sustain: 1000
  // default release: 500
  // if it gets 4000 the default should have a multiplier of 1
  
  float mediumLoud = 10000; 
  float outputMultiplier;
  
  
  // maps to -500x/(1.5 * 4000) + 1000 so it crosses 0 at 12000. hopefully totalLoud doesnt get that loud.
  if (totalLoud < 18900){
    outputMultiplier = ((-1) * totalLoud/mediumLoud) + 2;
    Serial.print("output multiplier: ");
    Serial.print(outputMultiplier);
    Serial.println();
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

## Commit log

2021-11-09 addin stuff
    [lil_duder-B_Cu.gbr, lil_duder-B_Mask.gbr, lil_duder-B_Paste.gbr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]
2021-11-11 switched power to 5v for speaker driver
    [lil_duder-B_Cu.gbr, lil_duder-B_Mask.gbr, lil_duder-B_Paste.gbr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]
2021-11-11 added timer and adc sample code
2021-11-15 added oscillator code: NOT TESTED
    [freq_detect.ino]
2021-11-30 fixing freq detect merge error
    [freq_detect.ino]
2021-12-08 changes to circuit
    [lil_duder-B_Cu.gbr, lil_duder-B_Mask.gbr, lil_duder-B_Paste.gbr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]
